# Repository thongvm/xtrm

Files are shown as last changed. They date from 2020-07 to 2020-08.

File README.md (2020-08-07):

# Xtrm

Extremely borderless mechanical keyboard PCB. 40% staggered layout with an encoder, runs [QMK firmware](https://github.com/myst729/qmk_firmware/tree/master/keyboards/dg/xtrm).



[On homemade keyboards](https://myst729.github.io/posts/2020/xtrm-40-keyboard/) (written in Chinese).

## Wiring

```
      C0      C1    C2    C3    C4    C5      C6    C7    C8     C9     C10       C11
   ,-------------------------------------------------------------------------------------.
R0 |  Esc  |  Q  |  W  |  E  |  R  |   T   |  Y  |  U  |  I  |   O    |  P   | Backspace |
   |-------+-----+-----+-----+-----+-------+-----+-----+-----+--------+------+-----------|
R1 |  Tab  |  A  |  S  |  D  |  F  |   G   |  H  |  J  |  K  |   L    |      |   Enter   |
   |-------+-----+-----+-----+-----+-------+-----+-----+-----+--------+------+-----------|
R2 | Shift |     |  Z  |  X  |  C  |   V   |  B  |  N  |  M  | RShift |  Up  | Caps Lock |
   |-------+-----+-----+-----+-----+-------+-----+-----+-----+--------+------+-----------|
R3 | Ctrl  | GUI |     | Alt |     | Space |     | Fn  | Fn2 |  Left  | Down |   Right   |
   `-------+-----+-----+-----+-----+-------+-----+-----+-----+--------+------+-----------'
```

## Tools

| Tool | Picture |
| --- | --- |
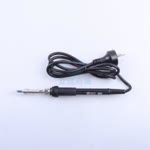
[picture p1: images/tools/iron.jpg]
| Soldering Iron (936) |  |
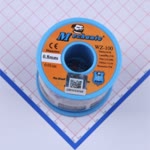
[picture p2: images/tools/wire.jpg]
| Soldering Wire (Sn63/Pb37, 0.8mm) |  |
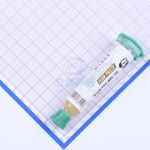
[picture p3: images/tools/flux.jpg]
| Soldering Flux |  |

## Materials

| Material | Label | Quantity | Picture |
| --- | --- | --- | --- |
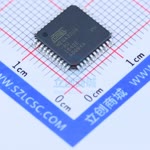
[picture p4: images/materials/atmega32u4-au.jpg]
| ATmega32U4-AU | U1 | 1 |  |
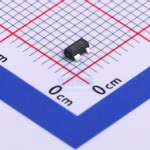
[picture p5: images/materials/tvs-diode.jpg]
| PRTR5V0U2X | U2 | 1 |  |
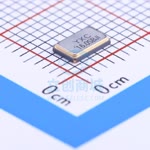
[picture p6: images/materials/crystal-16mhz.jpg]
| 16MHz Crystal | X1 | 1 |  |
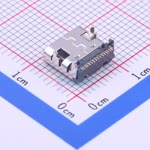
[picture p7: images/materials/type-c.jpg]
| Type-C Connector | CN1 | 1 |  |
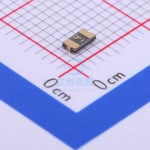
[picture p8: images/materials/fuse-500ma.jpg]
| 500mA Fuse | F1 | 1 |  |
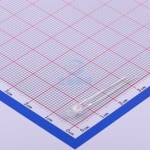
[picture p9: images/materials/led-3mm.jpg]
| 3mm LED | LED1 | 1 |  |
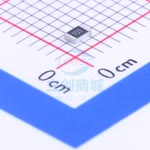
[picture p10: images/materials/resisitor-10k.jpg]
| 10KΩ Resistor | R3, R4, R6, R7, R10 | 5 |  |
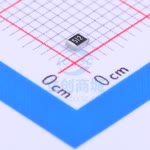
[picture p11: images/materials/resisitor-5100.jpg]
| 5.1KΩ Resistor | R2, R5 | 2 |   |
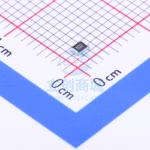
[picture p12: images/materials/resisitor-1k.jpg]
| 1KΩ Resistor | R1, R11 | 2 |  |
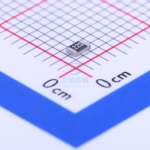
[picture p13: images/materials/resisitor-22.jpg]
| 22Ω Resistor | R8, R9 | 2 |  |
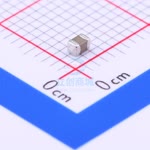
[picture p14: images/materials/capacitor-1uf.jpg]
| 1uF Capacitor | C6 | 1 |  |
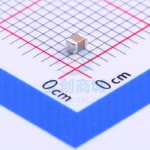
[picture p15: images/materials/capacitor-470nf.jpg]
| 470nF Capacitor  | C1 | 1 |  |
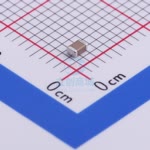
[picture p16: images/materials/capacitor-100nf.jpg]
| 100nF Capacitor  | C2, C3, C4, C5 | 4 |  |
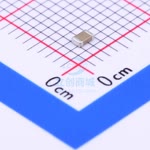
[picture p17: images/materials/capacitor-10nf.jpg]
| 10nF Capacitor | C7, C8 | 2 |   |
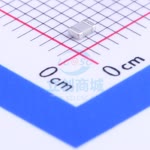
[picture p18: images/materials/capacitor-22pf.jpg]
| 22pF Capacitor | C9, C10 | 2 |   |
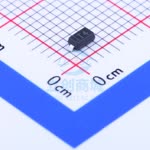
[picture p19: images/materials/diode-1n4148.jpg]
| 1N4148 Diode | D1-D43 | 43 |  |
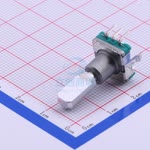
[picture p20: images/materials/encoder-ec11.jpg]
| EC11 Encoder | SW24 | 1 |  |
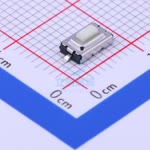
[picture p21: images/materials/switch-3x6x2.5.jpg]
| 3x6x2.5 Switch | KEY1 | 1 |   |

## Pictures

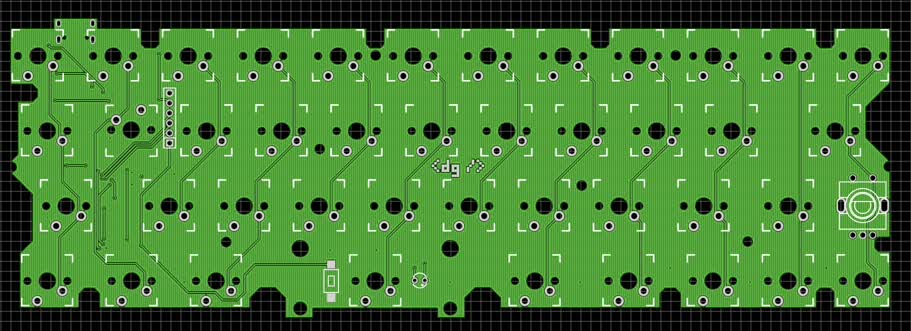
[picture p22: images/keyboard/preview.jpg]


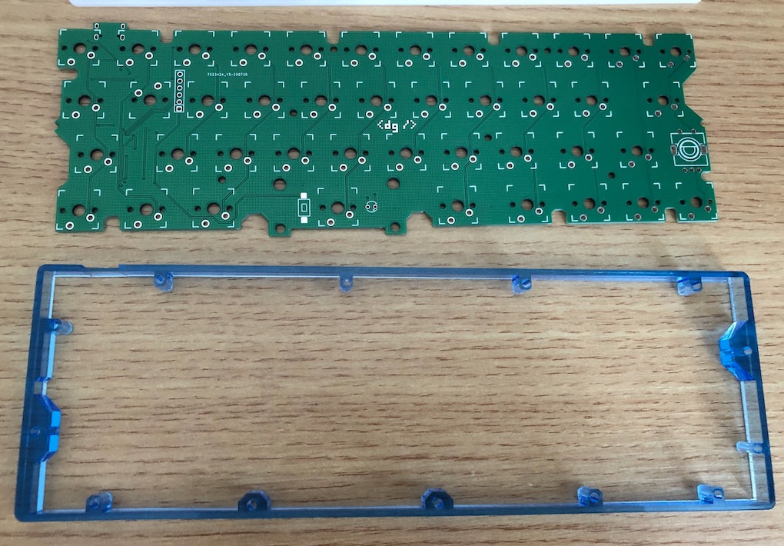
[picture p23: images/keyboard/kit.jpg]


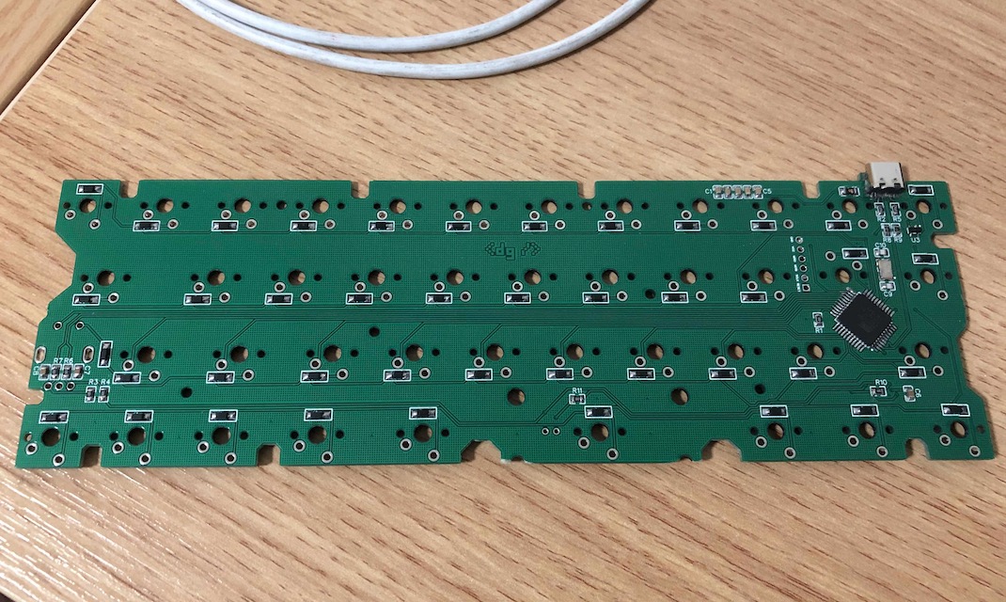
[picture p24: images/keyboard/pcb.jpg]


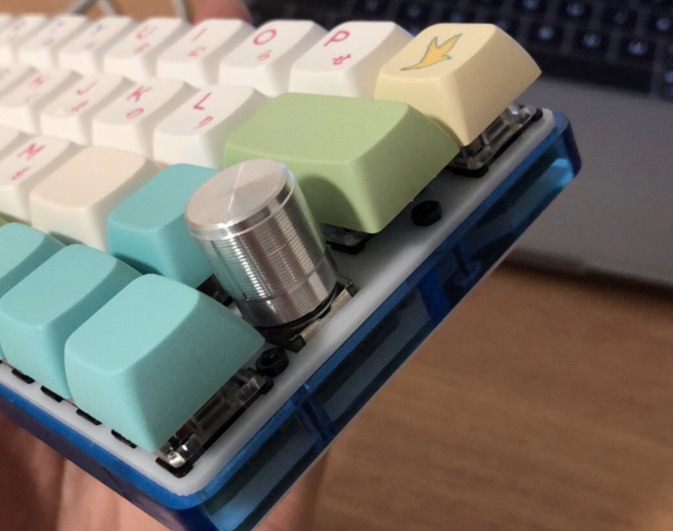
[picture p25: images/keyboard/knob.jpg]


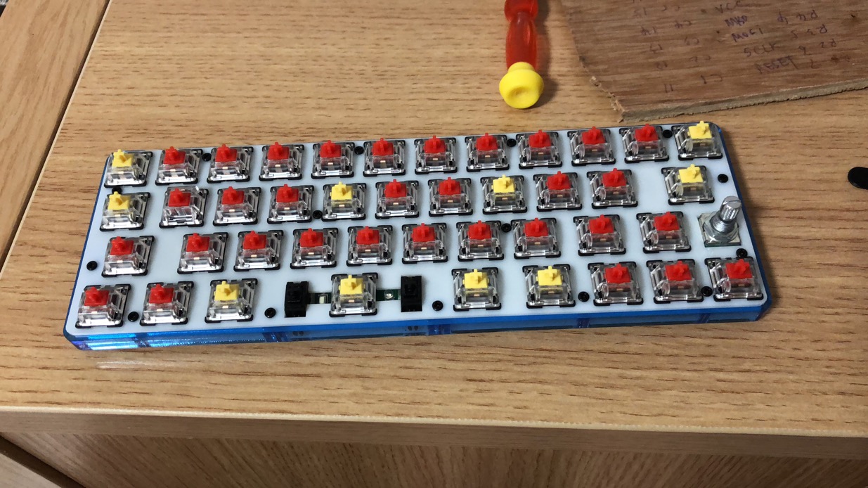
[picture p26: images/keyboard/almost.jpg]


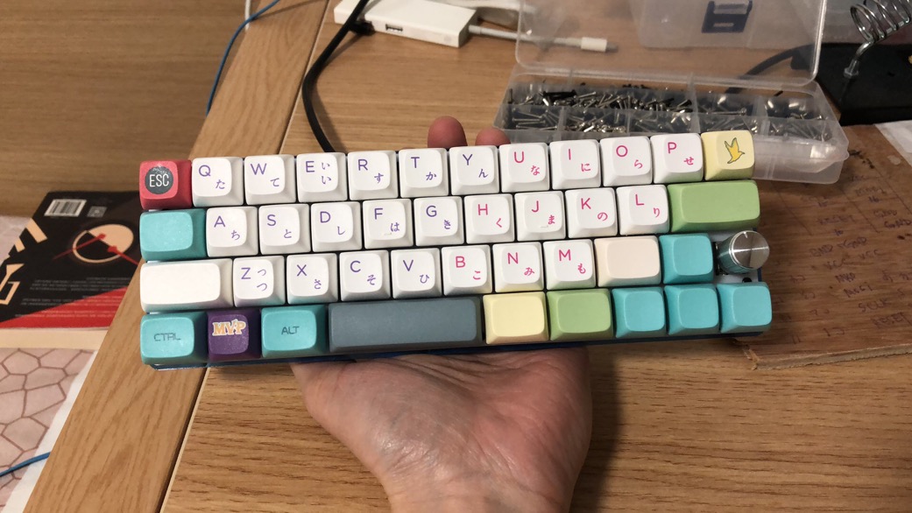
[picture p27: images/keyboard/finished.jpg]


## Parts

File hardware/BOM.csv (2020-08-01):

ID | Name | Designator | Footprint | Quantity | Manufacturer Part | Manufacturer | Supplier | Supplier Part
1 | ATMEGA32U4-AU | U1 | QFP-44_L10.0-W10.0-P0.80-LS13.2-BL | 1 | ATMEGA32U4-AU | MICROCHIP | LCSC | C44854
2 | PRTR5V0U2X | U2 | SOT-143_L2.9-W1.3-P1.92-LS2.3-BL | 1 | PRTR5V0U2X | Yenji Elec | LCSC | C330092
3 | 16MHz | X1 | OSC-SMD_4P-L5.0-W3.2-BL | 1 | X503216MSB4SI | Yangxing Tech | LCSC | C112586
4 | TYPE-C | CN1 | USB-C_SMD-TYPE-C-31-M-12 | 1 | TYPE-C-31-M-12 | Rectangular Connectors | LCSC | C165948
5 | 500mA | F1 | F1206 | 1 | MF-NSMF050-2 | BOURNS | LCSC | C75464
6 | 3mm | LED1 | LED-TH_BD3.8-P2.54-FD | 1 | 204-10SYGD/S530-E3 | EVERLIGHT | LCSC | C85161
7 | 10K | R3,R4,R6,R7,R10 | R0805 | 5 | RC0805JR-0710KL | YAGEO | LCSC | C100047
8 | 5.1K | R2,R5 | R0805 | 2 | RC0805JR-075K1L | YAGEO | LCSC | C105874
9 | 1K | R1,R11 | R0805 | 2 | RC0805JR-071KL | YAGEO | LCSC | C100046
10 | 22 | R8,R9 | R0805 | 2 | RC0805JR-0722RL | YAGEO | LCSC | C108406
11 | 1uF | C6 | C0805 | 1 | CL21B105KBFNNNE | SAMSUNG | LCSC | C28323
12 | 470nF | C1 | C0805 | 1 | CL21B474KBFNNNE | SAMSUNG | LCSC | C13967
13 | 100nF | C2,C3,C4,C5 | C0805 | 4 | CL21B104KBCNNNC | SAMSUNG | LCSC | C1711
14 | 10nF | C7,C8 | C0805 | 2 | CL21B103KBANNNC | SAMSUNG | LCSC | C1710
15 | 22pF | C9,C10 | C0805 | 2 | CL21C220JBANNNC | SAMSUNG | LCSC | C1804
16 | 1N4148 | D1-D43 | SOD-123_L2.8-W1.8-LS3.7-RD | 43 | FH1N4148W-JE | FH | LCSC | C105503
17 | EC11 | SW24 | SW-TH_EC11E18244A5 | 1 | EC11E18244A5 | ALPS Electric | LCSC | C255515
18 | SW-3x6x2.5 | KEY1 | KEY-SMD_L6.1-W3.7-LS8.0 | 1 | 1TS002E-2400-2500 | HYP | LCSC | C319365

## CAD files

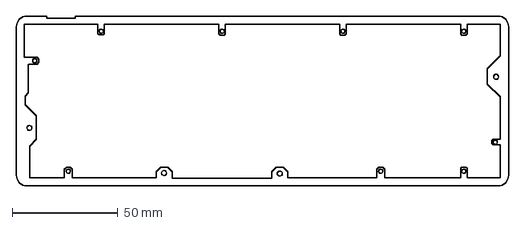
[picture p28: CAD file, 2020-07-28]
case/middle-frame-10mm.dxf
232.7 x 80.3 mm

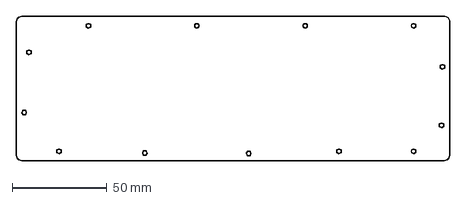
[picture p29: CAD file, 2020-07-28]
case/bottom-plate-1.5mm.dxf
228.6 x 76.2 mm

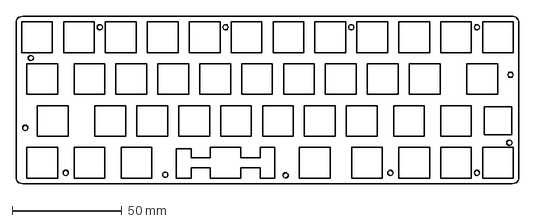
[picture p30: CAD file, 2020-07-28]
case/mounting-plate-1.5mm.dxf
228.6 x 76.2 mm

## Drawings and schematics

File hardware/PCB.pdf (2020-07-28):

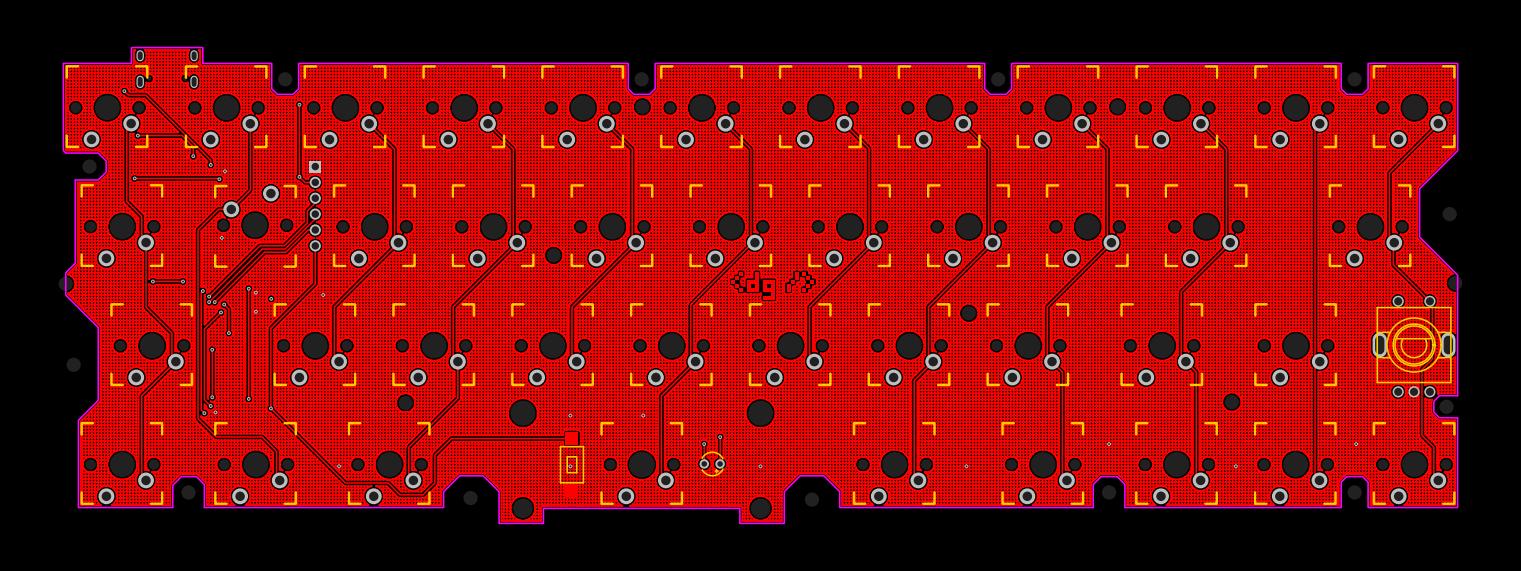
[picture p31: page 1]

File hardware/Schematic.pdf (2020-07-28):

<dg />

<dg />

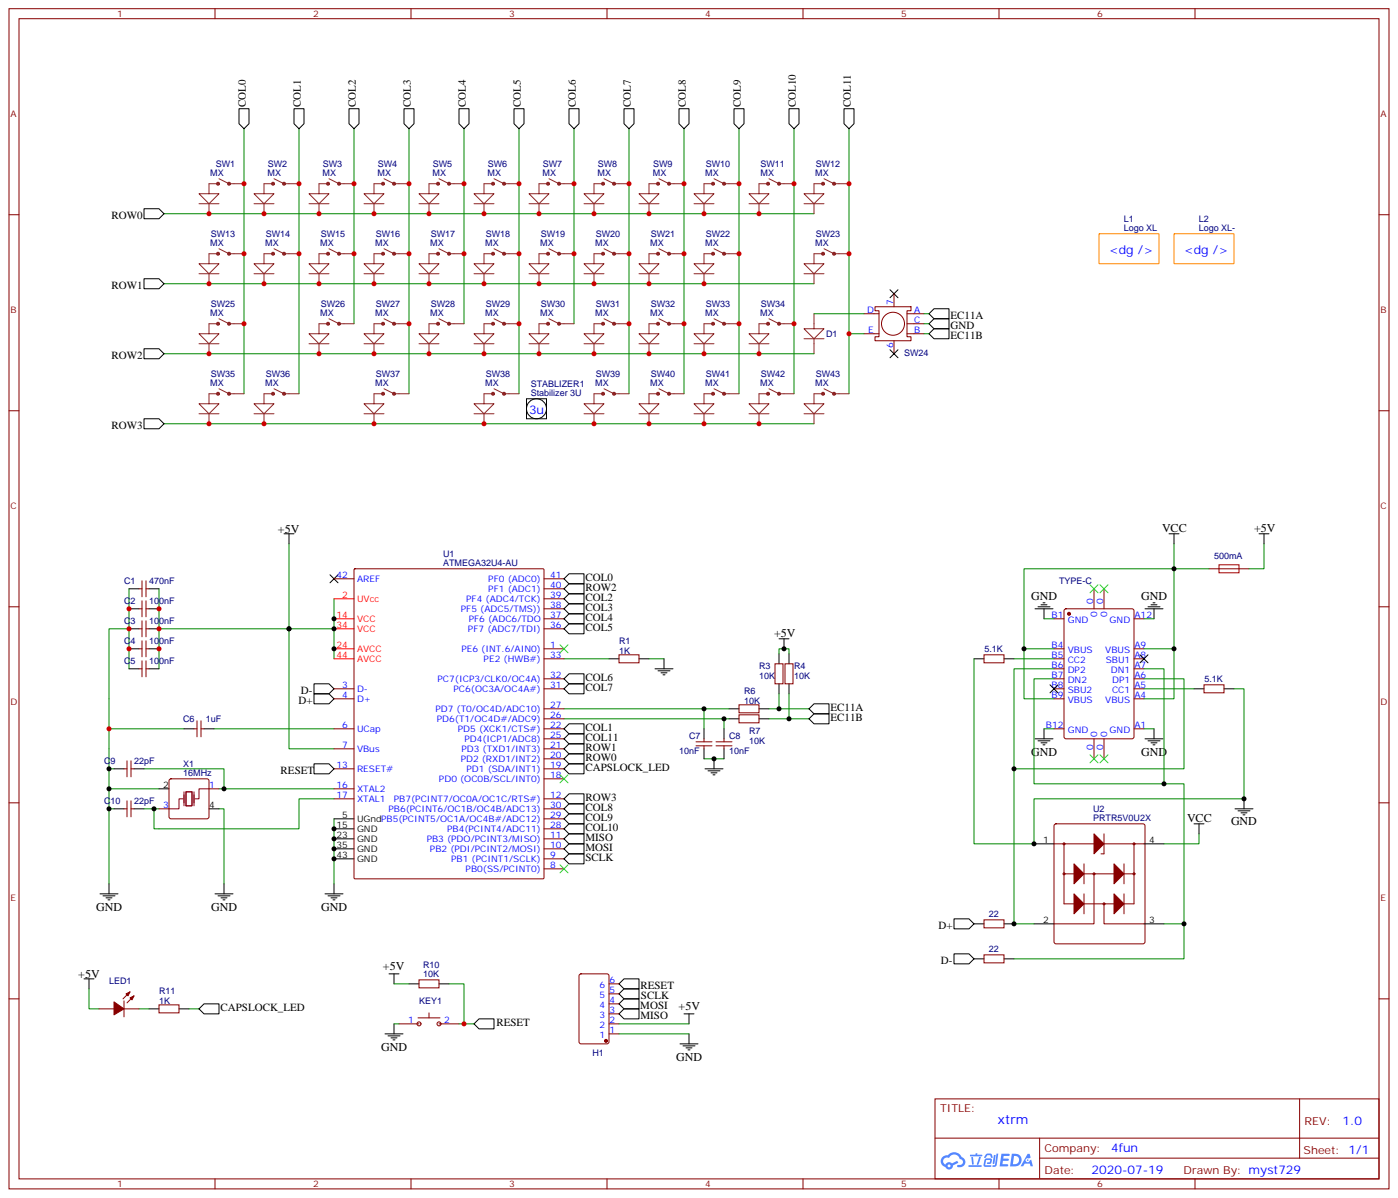
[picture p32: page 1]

PB7(PCINT7/OC0A/OC1C/RTS#) 12
PB2 (PDI/PCINT2/MOSI) 10 PB3 (PDO/PCINT3/MISO) 11 PB4(PCINT4/ADC11) 28 PB5(PCINT5/OC1A/OC4B#/ADC12) 29 PB6(PCINT6/OC1B/OC4B/ADC13) 30

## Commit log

2020-07-21 xtrm pcb
    [BOM.csv]
2020-07-22 add wiring
2020-07-28 fix copper, adjust case
    [bottom-plate-1.5mm.dxf, middle-frame-8mm.dxf, mounting-plate-1.5mm.dxf]
2020-07-31 add pictures of the finished keyboard
    [middle-frame-10mm.dxf, middle-frame-8mm.dxf]
2020-08-01 fix BOM
    [BOM.csv]
